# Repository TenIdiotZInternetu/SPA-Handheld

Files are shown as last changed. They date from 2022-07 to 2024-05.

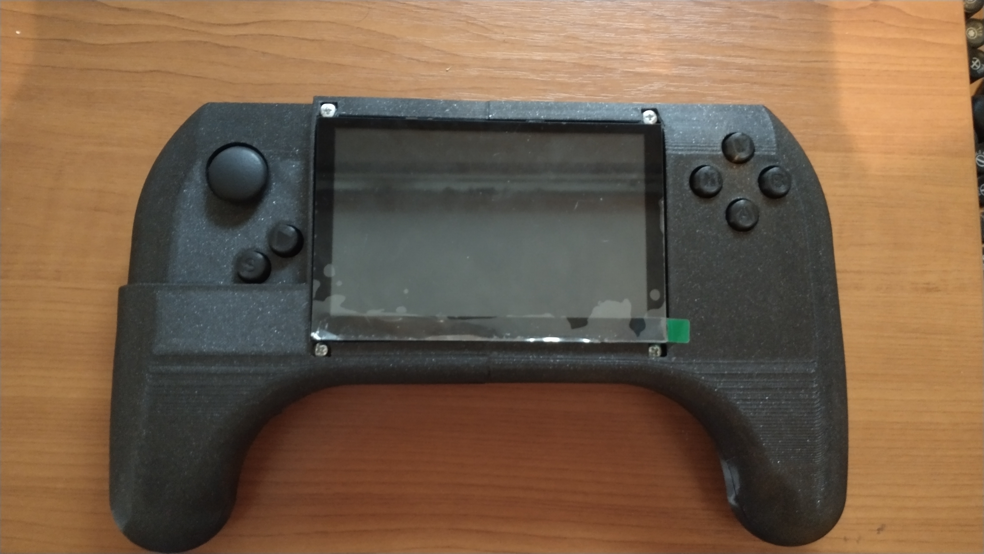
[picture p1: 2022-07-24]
IMG_20220422_183612783.jpg

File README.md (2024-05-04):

# SPA-Handheld

This is the main part of the Handheld Console project, a topic we chose for the Slovak Students' Professional Activities 2022.

All design files of the final product are contained here. The whole process of inspiration, designing PCB and 3D model and setting up the device is documented in the docx/pdf document.

## Subprojects

Task of the SPA included designing and programming the startup GUI and a game created in Pygame. Both found in the repos below.

* [**Bullet Hell (Videogame)**](https://github.com/TenIdiotZInternetu/SPA-Bullet-Hell)  
* [**GUI**](https://github.com/TenIdiotZInternetu/SPA-Bullet-Hell)

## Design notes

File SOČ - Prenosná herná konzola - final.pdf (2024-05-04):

STREDNÁ PRIEMYSELNÁ ŠKOLA STROJNÍCKA A ELEKTROTECHNICKÁ

ULICA FRAŇA KRÁĽA 20, 949 01 NITRA

PRENOSNÁ HERNÁ KONZOLA

Stredoškolská odborná činnosť

Číslo odboru: 11 informatika

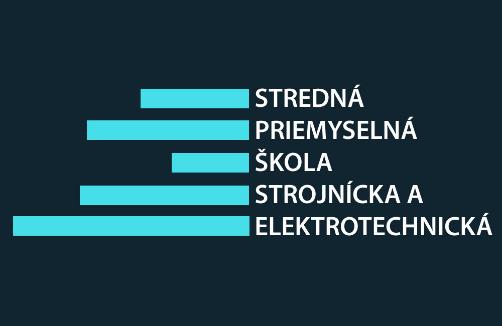
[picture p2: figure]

Riešitelia: Adam Balko

Jakub Brezovský

Nitra

2022

Ročník štúdia: štvrtý

STREDNÁ PRIEMYSELNÁ ŠKOLA STROJNÍCKA A ELEKTROTECHNICKÁ

ULICA FRAŇA KRÁĽA 20, 949 01 NITRA

PRENOSNÁ HERNÁ KONZOLA

Stredoškolská odborná činnosť

Číslo odboru: 11 informatika

Riešitelia: Adam Balko

Jakub Brezovský

Nitra

2022

Ročník štúdia: štvrtý

Školiteľ: PaedDr. Peter Antala

Čestné vyhlásenie

Vyhlasujeme, že prácu na tému Prenosná herná konzola sme vypracovali samostatne,

s použitím uvedených literárnych zdrojov. Sme si vedomí zákonných dôsledkov, ak v nej

uvedené údaje nie sú pravdivé.

Adam Balko | Jakub Brezovský

Poďakovanie

Touto cestou by sme sa chceli poďakovať školiteľovi práce PaedDr. Petrovi Antalovi za pomoc pri písaní a realizácii práce SOČ a taktiež Jakubovi Gálovi za užitočné rady pri jej

realizácii.

## OBSAH

ZOZNAM SKRATIEK A CUDZÍCH POJMOV

Bluetooth – protokoly pre bezdrôtovú komunikáciu na krátke vzdialenosti.

Boot – súbor procesov prebiehajúcich pri spúšťaní OS.

CAD (Computer Aided Design) – softvér na tvorbu 2D alebo 3D grafického znázornenia.

CAE (Computer Aided Engineering) – softvér určený na analýzy a simulácie.

CAM (Computer Aided Manufacturing) – softvér na vygenerovanie kódu pre CNC stroje.

Debian – jeden z operačných systémov dostupných pre Linux.

Debugovanie – kontrola funkčnosti programu a odstraňovanie chýb.

DPS – doska plošných spojov

DS (Dual Screen) – prenosná herná konzola od spoločnosti Nintendo.

DVD (Digital Video Disc) – optické pamäťové úložisko.

Emulátor – program pre spúšťanie softwaru na platformách, pre ktoré nebol určený.

FPS (Frames per Second) – počet vykreslených snímok za sekundu.

Game Boy – prenosná herná konzola od spoločnosti Nintendo.

GPIO (General-Purpose Input/Output) – rozhranie pre detekciu digitálnych výstupov a

vstupov Raspberry.

GUI (Graphical User Interface) – spôsob ovládania zariadenia cez grafické ikony

Handheld (z angl. „v rukách držaná“) – prenosná herná konzola.

Hard disk (Pevný disk) – magnetické pamäťové úložisko s veľmi veľkou kapacitou.

Hardware – fyzická časť počítača.

HDMI (High-Definition Multimedia Interface) – kábel pre prenos digitálneho zvuku a obrazu.

Hitbox – oblasť spritu schopná detegovať kolízie.

Image (obrázok) – vlastnosť spritu v Pygame, vizuálna reprezentácia objektu.

Joy-con – primárny herný ovládač konzoly Nintendo Switch.

Joystick / thumbstick – analógová kruhová ovládacia páka.

Linux – voľne šíriteľné jadro operačného systému.

Objekt – koncept v programovaní, dátový typ so špecifickými vlastnosťami a metódami.

OS – operačný systém.

Pin – krátky vodivý vývod konektora.

PIXEL (niekedy len „X“) – grafické užívateľské prostredie Raspberry Pi OS.

PSP (Playstation Portable) – prenosná herná konzola od spoločnosti Sony.

Pygame – sada modulov pre programovanie hier v Pythone.

Python – vysoko-úrovňový programovací jazyk.

Raspbian (Raspberry Pi OS) – odroda operačného systému Debian od Raspberry Pi.

RasPi (Raspberry Pi Zero 2 W) – jednodoskový mikropočítač.

Rect (rectangle, obdĺžnik) – vlastnosť spritu v Pygame, obsahuje jeho rozmery a polohu.

RetroPie – aplikácia, zbierka emulátorov starých herných konzol pre Raspberry Pi.

ROM (Read-Only Memory) – neprepisovateľná pamäť.

SD karta (Secure Digital Card) – flash pamäťové úložisko.

SDL (Simple DirectMedia Layer) – vývojová | knižnica | pre prácu | so vstupnými

a výstupnými zariadeniami.

Skript – krátky samostatne bežiaci program.

Software – programová časť počítača.

Sprite – sebestačný viditeľný objekt v Pygame.

SSH (Secure Shell) – protokol pre bezpečný prenos dát cez nechránené siete.

Switch (Nintendo Switch) – hybridná herná konzola od spoločnosti Nintendo.

Trieda (Class) – koncept v programovaní, definícia objektov rovnakého typu.

USB (Universal Serial Bus) – kábel pre komunikáciu a napájanie zariadení.

V (volt) – jednotka elektrického napätia.

Videohra – počítačová hra, digitálna hra.

Wi-Fi – protokoly pre lokálnu bezdrôtovú sieť.

WinSCP – program pre bezdrôtový prenos dát.

ZOZNAM ILUSTRÁCIÍ

SPŠSE Nitra | Úvod

8

ÚVOD

Videohry nás sprevádzajú už od detstva. Postupne prechádzala naša fascinácia z ich

hrania na vývoj a dizajn. S tým, samozrejme, prichádza aj záujem o herné konzoly

a počítače na ktorých bežia. Na elektrotechnickú strednú školu sme sa prihlásil práve

preto, aby sme nadobudli poznatky z hardwaru a softwaru, ktoré možno využijeme vo videohernom priemysle. Z tohto dôvodu sme si ako hlavnú tému našej práce SOČ vybrali

skonštruovanie vlastnej jednoduchej hernej konzoly, pre ktorú chceme vyvinúť aj vlastnú

videohru.

V predkladanej práci sa zameriavame na vývoj hardwarovej a softwarovej časti prenosnej

hernej konzoly. Pri písaní našej práce sme využívali poznatky zo štúdia na Strednej

priemyselnej škole strojníckej a elektrotechnickej v Nitre. Pri zhotovovaní zariadenia sme

čerpali najviac informácií z webových stránok a skúseností expertov na mikropočítače.

Hlavnou témou práce je zostrojenie prenosnej hernej konzoly, ktorá zahrňuje zbierku

emulátorov RetroPie, nami naprogramovanú hru v Pygame a grafické rozhranie schopné

spúšťať používateľom vytvorené hry.

Jednotlivé kapitoly našej práce postupne oboznámia čitateľa s problematikou prenosných

herných konzol, použitých aplikácií a mikropočítača Raspberry Pi, na ktorom bude celý

projekt pracovať. Popisujeme taktiež sadu modulov Pygame, aplikáciu RetroPie a softvéry

EAGLE a Fusion 360 ktoré sme použili pri vytváraní našej prenosnej hernej konzoly.

V druhej kapitole sú uvedené ciele našej práce a v ďalších kapitolách, ktoré sú určené pre

praktickú časť, popisujeme postup pri výrobe, vývoji, inštalácii, úprave a programovaní

aplikácií dôležitých pre dosiahnutie stanovených cieľov.

Sme toho názoru, že vytvorená prenosná herná konzola bude skvelým spôsob ako znova

prežiť svoje obľúbené hry z detstva, či už na cestách alebo z pohodlia domova, pričom

cenová dostupnosť a vysoká prispôsobiteľnosť Raspberry Pi s Linuxom ponúkne priestor

pre ďalšie experimentovanie a vylepšenie výrobku.

SPŠSE Nitra | Problematika a prehľad literatúry

9

### 1 PROBLEMATIKA A PREHĽAD LITERATÚRY

V prvej kapitole sa budeme venovať stručnej charakteristike herných konzol a oboznámime

čitateľov s jednodoskovým počítačom Raspberry Pi Zero 2 W, sadou modulov Pygame,

aplikáciou RetroPie a softvérmi EAGLE a Fusion 360, ktoré sme použili pri vytváraní našej

prenosnej hernej konzoly.

### 1.1 PRENOSNÁ HERNÁ KONZOLA

Herná konzola je elektronické zariadenie slúžiace na spúšťanie videohier z pamäťového

média (DVD, SD karta, Hard Disk, apod.), vysielanie audio a video signálu na výstupné

zariadenia (obrazovka, reproduktory) a ovládanie spustenej videohry pomocou herného

ovládača. Domáca herná konzola využíva externé vstupno-výstupné zariadenia.

Prenosná herná konzola (handheld) je typ hernej konzoly so zabudovanou obrazovkou,

ovládacími prvkami z herného ovládača, reproduktormi, poprípade inými vstupno-výstupnými

zariadeniami. Sú poháňane nabíjateľnými batériami a navrhované tak, aby boli čo

najkompaktnejšie. Na obrázku 1 je porovnanie veľkostí domácej hernej konzoly Playstation 4

(vľavo), jeho herného ovládača (v strede) a prenosnej konzoly Playstation Vita (vpravo).

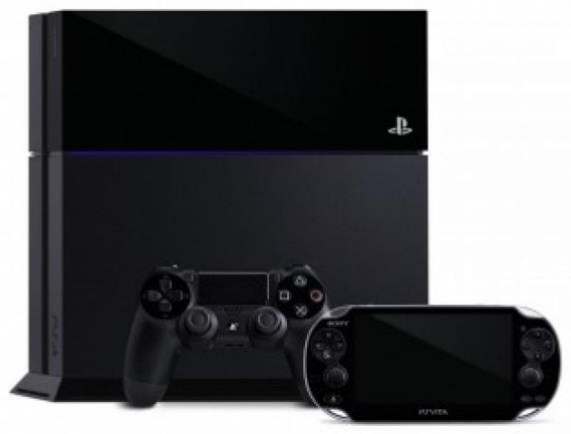
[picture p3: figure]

Obrázok 1 Domáca a prenosná herná konzola (playstationlifestyle, 2013)

Každý herný ovládač musí obsahovať tlačidlá na vykonávanie akcií špecifických pre danú

videohru. Od 90. rokov používajú všetky herné ovládače tzv. joysticky (niekedy tiež

thumbsticky). Sú to analógové zariadenia snímajúce vychýlenie páčky od stredu kruhovej

plochy pomocou 2 potenciometrov, 1 pre každú os pohybu. Pružina zaistí, aby sa páčka po

pustení vrátila do stredu kruhovej plochy. Novšie ovládače taktiež obsahujú prvky ako

SPŠSE Nitra | Problematika a prehľad literatúry

10

gyroskopy, vibračné motory, dotykový displej a iné. Výhodou herných konzol oproti

osobným počítačom (ktoré sú taktiež často používané na hranie videohier) je nižšia predajná

cena (väčšinou 300 – 500 €), garancia kompatibility medzi hardwarom a softwarom (čiže

elektronickými komponentami konzoly a videohrami) a minimálne zmeny v počiatočných

nastaveniach zariadenia. Používateľ však zaplatí nižším grafickým výkonom a nižším

počtom snímok za sekundu (bežne 30). Na hernej konzole taktiež nie je možné používať

profesionálny pracovný software. Handheldy sú typicky najlacnejšie a poskytujú najnižší

výkon, to však kompenzujú vyšším počtom vstupno-výstupných prvkov a schopnosťou hrať

videohry kdekoľvek a kedykoľvek.

Grafický výkon je dôležitý pre rýchle a verné vyobrazenie herného sveta, 2D a 3D animáciu,

simuláciu fyziky, výpočty spojené s hernými mechanizmami a umelou inteligenciou, čítanie

z pamäte, vykresľovanie obrazu na obrazovku a o mnoho viac. To všetko v reálnom čase.

Herné zariadenie musí byť schopné vykresliť na obrazovku aspoň 30 snímok každú sekundu

(FPS). To je minimálne množstvo potrebné na to, aby mozog nestihol reagovať na jednotlivé

snímky a vnímal ich ako plynulý pohyb. Vyššie FPS pre používateľa znamená, že hra reaguje

na jeho vstupy rýchlejšie. Naopak nižšie FPS spôsobuje trhavejší pohyb na obrazovke

a ťažšie ovládanie hry.

### 1.2 RASPBERRY PI ZERO 2 W

Raspberry Pi Zero 2 W (ďalej iba RasPi), je najnovší produkt z cenovo najdostupnejšej škály

jednodoskových mikropočítačov od Raspberry Pi (adafruit, 2021). Raspberry Pi Zero 2 W

uvedená na trh 28.10.2021 pri cene 15 $ ponúka až 5-násobný výkon svojho predchodcu

Označenie „W“ predstavuje schopnosť pripojenia k sieti Wi-Fi a Bluetooth.

Špecifikácie Raspberry PI Zero 2 W:

- 1GHz 4-jadrový 64-bit ARM procesor Cortex-A53,
- 512MB SDRAM,
- OpenGL ES 1.1, 2.0 grafické rozhranie,
- Porty: Mini HDMI, 2x Micro USB,
- CSI-2 konektor na kameru,
- 40-pinové GPIO rozhranie,
- 65mm x 30mm.

SPŠSE Nitra | Problematika a prehľad literatúry

11

Na činnosť je potrebný 5 V napäťový zdroj a Micro SD karta s vopred napáleným OS na báze

Linuxu. Raspberry Pi ponúka a odporúča odrodu Linuxovej distribúcie Debian,

Raspberry Pi OS, bežne nazývaný Raspbian (raspberrypi.com). SD karta slúži ako úložisko

pre všetky dáta na RasPi. Pre bežné použitie je nutné pripojiť obrazovku cez Mini HDMI

a klávesnicu na používanie terminálu cez Micro USB. V prípade negrafických aplikácii je

s RasPi možné komunikovať bezdrôtovo cez protokol SSH z osobného počítača. Veľmi

užitočné je rozhranie GPIO, ktoré slúži na prijímanie a odosielanie 3.3 V digitálnych signálov

napríklad zo snímačov, tlačidiel, LED, integrovaným obvodom apod.

Grafické jadro Broadcom VideoCore IV podporuje OpenGL 1.1, 2.0, ako aj dekódovanie

videa H.264, MPEG-4. Maximálne rozlíšenie je 1920 x 1080 pixelov, čiže full HD. Na

pripojenie monitora je k dispozícií mini HDMI konektor. Treba počítať aj s tým, že pamäť

512 MB je zdieľaná s grafickým jadrom, čiže operačný systém má k dispozícií len

približne 450 MB. Na obrázku 2 je popis pinov Raspberry PI Zero 2 W.

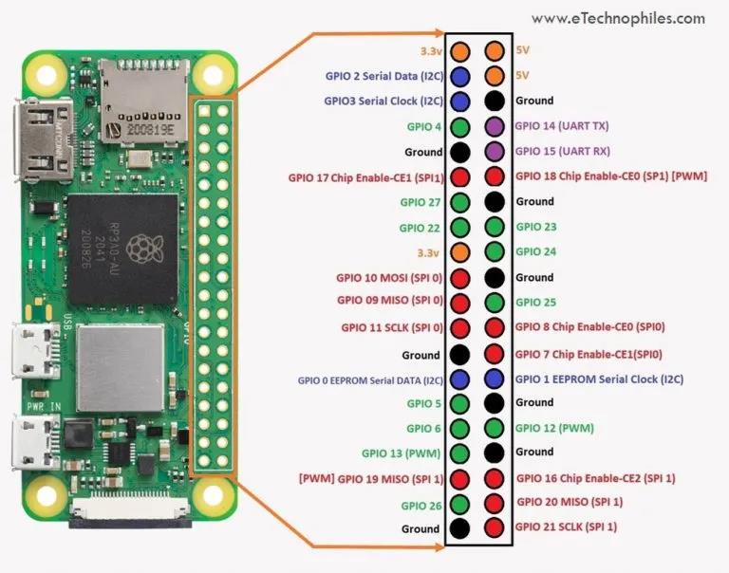
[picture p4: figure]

Obrázok 2 Raspberry PI Zero 2 W (eTechnophiles, 2022)

SPŠSE Nitra | Problematika a prehľad literatúry

12

### 1.3 PYGAME

Pygame je sada modulov pre programovací jazyk Python navrhnutých pre vývoj

videohier. Pygame pridáva funkcionalitu existujúcej knižnice SDL (pygame.org, 2022).

SDL je „multi-platformová vývojová knižnica navrhnutá pre nízkoúrovňový,“ (na úrovni

hardwaru), „prístup k audiu, klávesnici, myši, hernému ovládaču a grafickému hardwaru

skrz OpenGL a Direct3D“ (libsdl.org, 2022). Známe hry vytvorené pomocou knižnice

SDL sú napríklad Factorio alebo hry od spoločnosti Valve.

Základom každej hry je nekonečná slučka. V každom cykle tejto slučky Pygame číta

udalosti zo vstupných zariadení pomocou SDL, spracuje ich v používateľom napísaných funkciách a vykreslí nové informácie do okna, ktoré vytvoril. Dĺžka každého cyklu sa

určuje podľa požadovaného počtu FPS.

Dôležitým konceptom Pygame je trieda Sprite. Objekty, ktoré dedia z tejto triedy

predstavujú každú sebestačnú viditeľnú entitu, ktorou bude Pygame aplikácia

manipulovať, napríklad postavy, projektily, prvky používateľského rozhrania apod. Na

rozdiel od všeobecného pojmu, sprite v Pygame obsahuje okrem vizuálnej reprezentácie

objektu (image) aj informácie o jeho polohe a rozmeroch (rect), a metódu update, ktorá

prikazuje spritu ako sa chovať v každom cykle nekonečnej slučky.

Sprity podobného typu je možné priraďovať do dátovej štruktúry Group, ktorá umožňuje

masovo updatovať viacero spritov naraz, ako aj jednotlivými spritmi iterovať.

### 1.4 RETROPIE

RetroPie je aplikácia, ktorá buduje na Raspbian, EmulationStation, RetroArch a mnoho

ďalších projektoch, aby umožnil hranie arkádových, konzolových a klasických

počítačových hier s minimálnou prípravou. (retropie, 2022)

RetroArch a EmulationStation sú front-end programy pre prácu s emulátormi herných

konzol. Prinášajú grafické používateľské rozhranie, jednoduché spúšťanie emulovaných

hier, širokú škálu nastavení pre plynulý pochod programov a funkcionalitu nad rámec

pôvodných zariadení.

Emulátor je hardware alebo software, umožňujúci jednému počítačovému systému

(nazývanému hostiteľ) chovať sa ako iný počítačový systém (zvaný hosť). Emulátor

SPŠSE Nitra | Problematika a prehľad literatúry

13

typicky dovoľuje hostiteľovi spustiť software alebo používať periférne zariadenia

pôvodne navrhnuté pre hosťovský systém. (wikipedia – a, 2022)

RetroPie združuje mnoho emulátorov, medzi inými aj pre pôvodný Game Boy, a knižníc

potrebných pre vysokú kompatibilitu s počítačmi Raspberry Pi. Ovládateľný je širokou

škálou herných ovládačov alebo klávesnicou, ktoré sa dajú v rámci aplikácie

konfigurovať. RasPi je svojím výkonom schopné emulovať konzoly 2. až 5. generácie

(koniec 70-tych až koniec 90-tych rokov).

Samotné hry sú inštalované formou ROM obrazov. Ide o počítačové súbory obsahujúce

kópiu dát z ROM (Read-Only Memory) čipu, často z videoherných diskiet (wikipedia - b,

2022). Na používanie stačí ROM obrazy skopírovať v správnom formáte do priečinku

prislúchajúcemu konkrétnemu emulátoru.

### 1.5 EAGLE

EAGLE je návrhový softvér pre elektroniku od spoločnosti Autodesk, ktorý umožňuje

vytvoriť návrh DPS podľa schémy zapojenia a následne umožňuje vygenerovať dáta pre

výrobu samotnej DPS.

Samostný softvér sa skladá z editora schém, editora plošných spojov a editora knižníc.

Editor schém slúži na vytvorenie schémy zapojenia s možnosťou simulátora, vytvorenia

blokov a s elektronickou kontrolou nastavených pravidiel. Editor plošných spojov

synchronizuje schému s návrhom, poskytuje kontrolu návrhových pravidiel a pomocou

ďalších nástrojov výrazne zjednodušuje proces návrhu DPS. Editor knižníc obsahuje

databázu prvkov potrebných pre vytvorenie schémy návrh DPS.

### 1.6 FUSION 360

Fusion 360 je cloudový softvér od firmy Autodesk pre 3D CAD, CAM, CAE

modelovanie. Umožňuje vyvíjať výrobok v celom jeho procese od skice, cez návrh 3D

modelu, jeho testovanie, simulácie, vizualizácie až po výrobu. Pri modelovaní sa vytvára

časová os. Fusion 360 obsahuje nástroje, ktoré umožňujú skicovanie, priame

modelovanie, modelovanie povrchu, parametrické modelovanie, modelovanie sieťoviny,

voľné modelovanie, vykresľovanie, integráciu návrhu DPS, prácu s plechmi a zostavami.

Keďže je Fusion 360 kompatibilný s programom EAGLE, tak umožňuje do 3D modelu

importovať model našej DPS.

SPŠSE Nitra | Ciele práce

14

### 2 CIELE PRÁCE

Vlastniť prenosnú hernú konzolu bolo snom takmer každého chlapca. Avšak postupom

času sa pre nás stal záujmom nového poznania fakt, ako tieto malé zariadenia fungujú.

V súčasnosti, keď je možné vďaka pokroku zostrojiť doma vlastnú hernú konzolu, bolo

pre nás výzvou spolupodieľať sa na vytvorení takéhoto zariadenia.

Hlavným cieľom ktorý sme si stanovili pre našu prácu bolo zostrojiť prenosnú hernú

konzolu. Popri hlavnom ciele našej práce sme si stanovili aj nižšie uvedené čiastkové

ciele.

Čiastkové ciele:

- stručne | oboznámiť | čitateľov | s vysvetlením | pojmu | herná | konzola

a charakteristikou Raspberry PI Zero 2 W, Pygame a RetroPie,

- zostrojiť hernú konzolu s riadením pomocou Raspberry PI Zero 2 W,
- na vizuálne zobrazenie použiť 5" displej HDMI 800x480,
- ovládanie hernej konzoly zabezpečiť prostredníctvom joysticku a tlačidiel,
- ako pamäťové úložisko použiť SD kartu na Raspberry,
- prostredníctvom 3D tlače vytvoriť konštrukčné prvky hernej konzoly
- vytvoriť vlastné grafické používateľské rozhranie,
- umožniť spúšťanie hier naprogramovaných v Pygame,
- vytvoriť jednoduchú hru v Pygame,
- integrovať emulátor retro hier RetroPie.

SPŠSE Nitra | Materiál a metodika

15

### 3 MATERIÁL A METODIKA

V tretej kapitole našej dokumentácie sa zameriame na postup výroby hernej konzoly,

postup pri inštalácii operačného systému a niektorých dôležitých aplikácii. Popíšeme

prácu s Raspberry Pi a vývoj jednoduchej videohry pomocou Pygame.

### 3.1 BLOKOVÁ SCHÉMA PRENOSNEJ HERNEJ KONZOLY

Výrobnej fáze predchádzala prípravná fáza, ktorej podstatou bolo získavanie informácií a

materiálu pre náš projekt. Začiatkom výrobnej fázy bol nákres schémy v programe EAGLE,

návrh DPS a prvé pokusy o 3D model obalu. Súbežne s modelovaním obalu pracovali na vývoji

softvéru, zadali DPS do výroby a následne sme ju osádzali jednotlivými súčiastkami. Na

obrázku 3 je bloková schéma zariadenia. Podrobná schéma sa nachádza v Prílohe A.4.

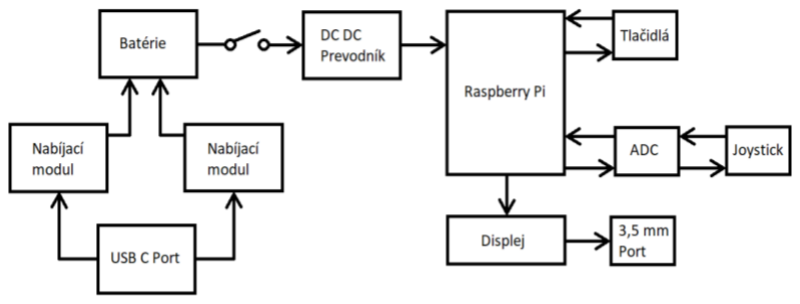
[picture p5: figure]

Obrázok 3 Bloková schéma prenosnej hernej konzoly

USB C port - slúži na prívod elektrickej energie do obvodov konzoly.

Nabíjacie moduly - nabíjajú batérie vhodným napätím.

Batérie - mobilné napájanie obvodu.

DCDC prevodník - znižuje jednosmerné napätie z batérií, chráni obvod pred

nedovoleným napätím.

Raspberry Pi – jadro celého obvodu, mikropočítač.

Displej – zobrazovacia jednotka.

3,5 mm port – audio výstup pre slúchadlá.

ADC (analog to digital converter) – prevádza analógový signál z joysticku na digitálny a naopak.

Joystick – vysiela analógový signál do ADC, spôsob pohybu v hre.

Tlačidlá - vysielajú digitálny signál do Raspberry Pi, rôzne funkcie v hre.

SPŠSE Nitra | Materiál a metodika

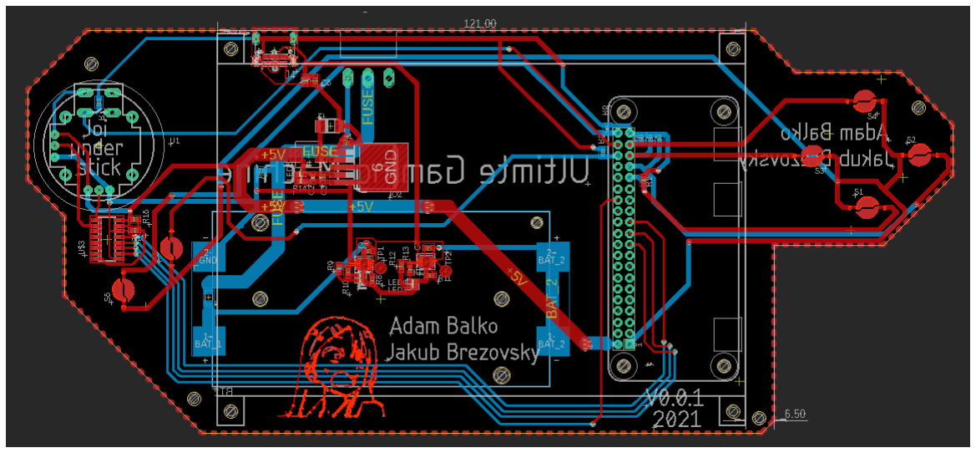
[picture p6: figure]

16

### 3.2 DOSKA PLOŠNÝCH SPOJOV

Návrh DPS sme realizovali pomocou návrhového softvéru pre elektroniku - EAGLE. Začali

sme nákresom schémy a následne sme prešli k návrhu samotnej DPS. Ako prvé sme načrtli

pôdorys displeja do stredu dosky. Napravo od displeja sme umiestnili primárne tlačidlá, zatiaľ

čo na ľavú stranu sme umiestnili joystick a systémové tlačidlá. Spínač, rovnako ako USB-C a

3,5 mm port sme umiestnili na horný okraj DPS. Socket pre batérie sme pre jeho veľké rozmery

umiestnili na spodnú stranu DPS.

Pre tlačidlá sme vytvorili vlastnú knižnicu v EAGLE editore súčiastok. Aby sa uhlíková vložka mohla dotýkať vodivých častí tlačidla, celý jeho povrch je potrebné označiť vrstvou tStop. Časti

dosky označené touto vrstvou nebudú pri výrobe pokryté izolačnou vrstvou (obrázok 4).

Obrázok 4 Návrh DPS

Keďže je nutné, aby bola DPS dvojvrstvová, nevyrábali sme ju sami, ale nechali sme ju na

mieru vyrobiť cez JLCPCB.com. Pre objednávku je potrebné nahrať súbor DPS v Gerber

formáte. Gerber súbory obsahujú všetky informácie potrebné pre výrobu DPS, ako napríklad umiestnenie dier, cestičiek, rozmery dosky, a pod. Úplný postup vytvárania

Gerber súboru nájdeme na stránke https://support.jlcpcb.com/article/137-how-to-generate-

gerber-and-drill-files-in-autodesk-eagle. (https://support.jlcpcb.com/article/137-how-to-generate-gerber-and-drill-files-in-autodesk-eagle) Po nahratí Gerber súboru sme ďalšie nastavenia

na stránke nemenili a objednávku sme potvrdili. Doska dorazila do 14 dní. Hotová DPS je

na obrázku 5.

SPŠSE Nitra | Materiál a metodika

17

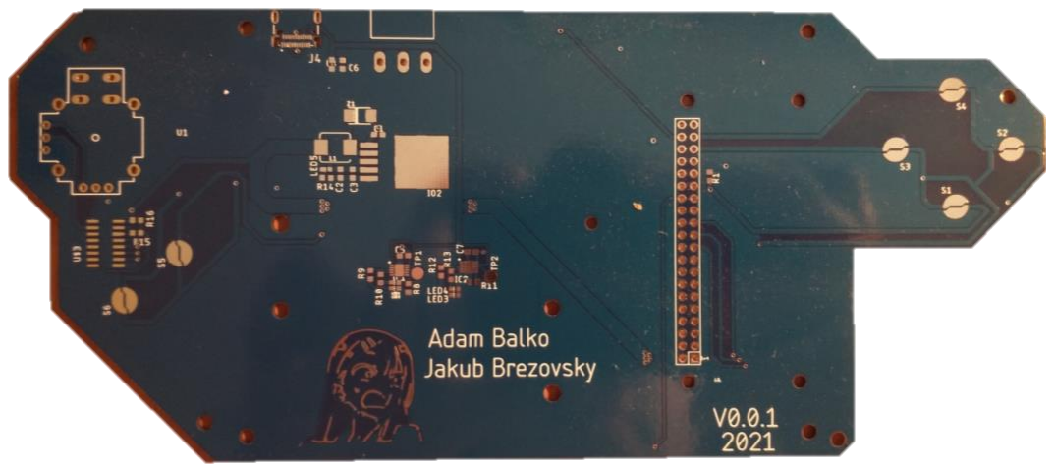
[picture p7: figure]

Obrázok 5 Vyrobená DPS

### 3.3 PRÍPRAVA PRE PRÁCU S RASPBERRY PI

Pre správne používanie RasPi pre naše účely je potrebné nainštalovať OS, nadviazať

bezdrôtové spojenie pomocou WinSCP a pozmeniť niektoré nastavenia. To si bližšie

popíšeme v tejto kapitole.

### 3.3.1 Inštalácia operačného systému

Prvým krokom je napálenie OS na SD kartu. Začneme inštaláciou na našu pracovnú stanicu

(napr. PC) Raspberry Pi Imager zo stránky https://www.raspberrypi.com/software/. SD

kartu vsunieme do čítačky SD na pracovnej stanici. Spustíme Raspberry Pi Imager.

V ponuke „CHOOSE OS“ si zvolíme podponuku „Raspberry Pi OS“ a možnosť

„Raspberry Pi OS (Legacy)“. RetroPie v dobe písania tejto dokumentácie nie je

prispôsobený verzii Raspbianu Bullseye z roku 2021 a nebude nainštalovaný úspešne.

Legacy znamená, že bude napálená staršia verzia Raspbian Buster. V ponuke

„CHOOSE STORAGE“ zvolíme našu SD kartu.

Klikneme na ikonu ozubeného kolieska a zaškrtneme nasledovné kolónky:

- „Enable SSH“
- „Set username and password“ a vložíme ľubovoľné prihlasovacie údaje
- „Configure wifi“ a vložíme prihlasovacie údaje wi-fi siete ku ktorej sa chceme

pripojiť

- „Set locale settings“ a zvolíme Keyboard layout „us“

Uložíme pomocou tlačidla „SAVE“ a OS napálime tlačidlom „WRITE“. Počkáme

niekoľko minút, kým sa OS napáli.

SPŠSE Nitra | Materiál a metodika

18

Po napálení otvoríme súbor boot/config.txt na SD karte podľa stránky našej HDMI

obrazovky (waveshare.com) doplníme na koniec nasledujúce riadky.

### 3.3.2 Nastavenie a používanie terminálu

SD karta je pripravená na vsunutie do RasPi. Po prepnutí vypínača na konzole sa na

obrazovke zobrazí výzva k zadaniu používateľského mena a hesla. Ide o rovnaké

prihlasovacie údaje, ktoré sme uviedli do sekcie „Set username and password“ pri

napaľovaní OS. Nabootuje sa PIXEL, grafické používateľské prostredie Raspbian.

RetroPie nie je možné spustiť, kým je PIXEL spustený. Riešením je nastaviť RasPi tak,

aby pri boote preskočil načítanie pracovnej plochy.

Na to musíme otvoriť terminál pomocou klávesovej skratky Ctrl+Alt+T. Použijeme

príkaz sudo raspi-config pre otvorenie nastavení RasPi. Zvolíme možnosti

„1 System Options“ > “S5 Boot / Auto Login” > “B2 Console Autologin” a potvrdíme

tlačidlom „<Finish>“. Pri výzve o reboot systému zvolíme možnosť „<Yes>“.

Od tohto momentu sa RasPi bude bootovať do príkazového riadku a nebude vyžadovať

prihlasovacie údaje. Dôležité príkazy pre navigáciu v termináli zahŕňajú:

- cd <názov priečinku> - vstup do priečinku
- cd .. – návrat do predchádzajúceho priečinku
- ls – výpis súborov v priečinku
- sudo <príkaz> - vykonanie príkazu ako správca (tzv. root)
- apt-get install <názov programu> - inštalácia programu z dpkg

databázy programov pre Linux

- git clone <url> - stiahnutie zdrojového kódu z databázy git
- python3 <.py súbor> - spustenie zdrojového kódu jazyka Python
- pip3 install <názov modulu> - inštalácia modulu pre jazyk Python
- sudo nano <názov súboru> - úprava textových súborov
- startx – vstup do pracovnej plochy PIXEL
- sudo raspi-config – vstup do nastavení RasPi

SPŠSE Nitra | Materiál a metodika

19

Pre používanie príkazov pip3 a git je ich najprv potrebné nainštalovať príkazmi sudo

apt-get install python3-pip a sudo apt install git.

### 3.3.3 Pripojenie pomocou SSH

SSH nám poslúži na zdieľanie súborov medzi pracovnou stanicou a RasPi, a na vzdialený

prístup k terminálu RasPi. Našou voľbou programu pre prácu s SSH je WinSCP pre jeho

jednoduchosť | a intuitívne | prvky. | Stiahnuť | ho | je | možné | zo | stránky

https://winscp.net/eng/download.php.

Po spustení nás uvíta prihlasovacie okno. Do kolónky „Host name“ vpíšeme lokálnu IP

adresu nášho RasPi. Zistiť ju môžeme pomocou príkazu ifconfig v termináli RasPi. Do

kolóniek „User name“ a „Password“ doplníme prihlasovacie údaje,. V kolónke „Port

number“ necháme číslo 22.

Niektoré príkazy vyžadujú oprávnenie správcu. To získame kliknutím na ponuku

„Advanced“ a zvolením podponuky „Shell“. Spomedzi možností ponuky „Shell“

vyberieme „sudo su -“. Klikneme na tlačidlo „OK“. Naše nastavenia uložíme pomocou

tlačidla „Save“ a pomocou tlačidla „Login“ sa spojíme s naším RasPi. Nadviazať spojenie

je možné iba ak je RasPi už spustené.

Celé používateľské rozhranie je na obrázku 6. Na ľavej strane vidíme súbory našej pracovnej

stanice. Na pravej strane vidíme súbory nachádzajúce sa na SD karte RasPi. Terminál môžeme

otvoriť pomocou ikonky terminálu v druhom riadku, alebo klávesovou skratkou Shift+Ctrl+T.

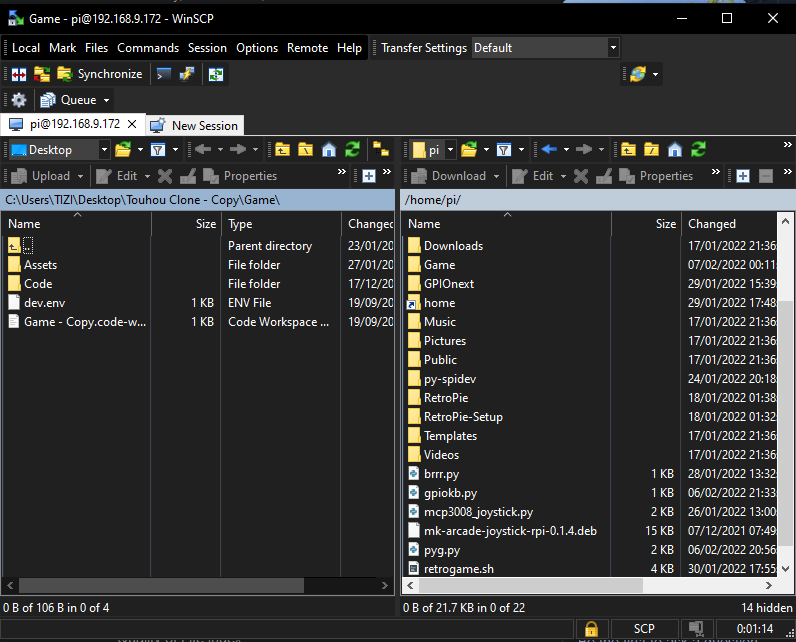
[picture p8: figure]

Obrázok 6 Používateľské rozhranie WinSCP

SPŠSE Nitra | Materiál a metodika

20

### 3.4 INŠTALÁCIA EMULÁTORA RETROPIE

V nasledujúcej kapitole si ukážeme, ako nainštalovať RetroPie a nastavenie GPIO pinov.

### 3.4.1 Konfigurácia GPIO vstupov

RetroPie nemá zabudované čítanie s GPIO vstupov, ku ktorým sú pripojené naše tlačidlá.

Jedným riešením je napísať externý skript, ktorý bude simulovať vstupy klávesnice, keď

sa bude na GPIO pine nachádzať napätie. Tento skript bude vždy bežať na pozadí.

Využijeme Python moduly keyboard a RPi.GPIO. Modul keyboard je potrebné

nainštalovať pomocou príkazu pip3 install keyboard. Na čítanie vstupov z ADC cez

SPI zbernicu sme využili modul Adafruit MCP3xxx, ktorý sme stiahli príkazom pip3

install adafruit-circuitpython-mcp3xxx. Časť kódu na detekciu analógových

vstupov je vidieť na obrázku 7.

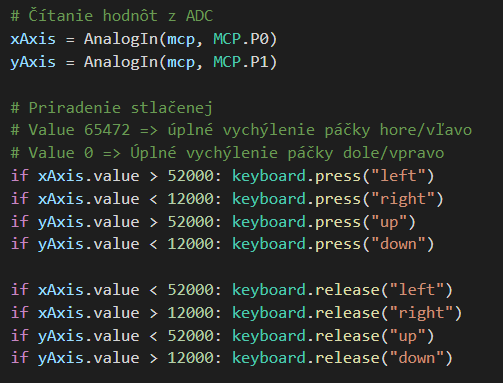
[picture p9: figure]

Obrázok 7 Časť skriptu gpiokb.py

Na používanie SPI zbernice je potrebné zmeniť mód pinov 9, 10 a 11 na alternatívny

vstup 0 vždy po boote RasPi. Uskutočníme tak v bash skripte, ktorého obsah je na

obrázku 8. Pred samotnou zmenou módu sme nastavili čakanie 20 sekúnd, aby sme

predišli zmene módu naspäť na východzí a inému nežiadanému správaniu.

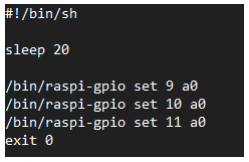
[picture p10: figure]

Obrázok 8 Skript setspi.sh

Súbory so skriptami nahráme do RasPi pomocou WinSCP. Aby spustili hneď pri boote

RasPi dopíšeme príkazy na ich spustenie do systémového súboru /etc/rc.local nad riadok

SPŠSE Nitra | Materiál a metodika

21

exit 0. | Ide | konkrétne | o príkazy | sudo python3 /home/pi/gpiokb.py &

a bash /home/pi/setspi.sh &.

### 3.4.2 Konfigurácia RetroPie

Pri inštalácii dodržujeme postup uvedený na stránke https://retropie.org.uk/docs/Manual-

Installation/. (https://retropie.org.uk/docs/Manual-Installation/) Pred inštaláciou programov je väčšinou vhodné aktualizovať OS príkazom

sudo apt update && sudo apt upgrade, no keďže RetroPie nie je kompatibilný

s najnovšou verziou Raspbian Bullseye, tento krok ignorujeme. Pokračujeme zmenou

lokalizačných nastavení a následným spustením inštalátora RetroPie podľa obrázku 9.

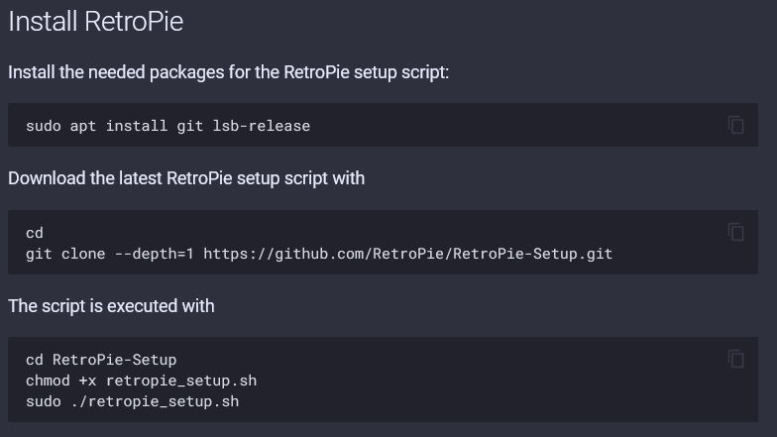
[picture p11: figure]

Obrázok 9 Postup pri spúšťaní inštalátora RetroPie (retropie, 2022)

Jednotlivé komponenty RetroPie sa dajú nainštalovať samostatne v sekcii „Manage

Packages“, no pre našu aplikáciu je vyhovujúce spustiť základnú inštaláciu možnosťou

„Basic Install“. Zvyšok inštalácie prebieha automaticky a trvá približne 6 až 8 hodín.

Po dokončení inštalácie spúšťame RetroPie z terminálu príkazom emulationstation.

Po prvom spustení sa nám zobrazí okno pre konfiguráciu vstupného zariadenia.

Podržaním ktoréhokoľvek z tlačidiel by mal program detegovať zariadenie

„KEYBOARD“, čiže klávesnicu. Nasleduje zoznam vstupov, tak ako na obrázku 16. Pri

každom z nich stlačíme prislúchajúce tlačidlo. V prípade „D-PAD“ tlačidiel posunieme

joystick do prislúchajúceho smeru. V prípade možnosti „HOTKEY ENABLE“ stlačíme

joystick. Pre vstupy nenachádzajúce sa na našom ovládači podržíme akékoľvek

z tlačidiel. V prípade chyby je možné vykonať konfiguráciu vstupov z hlavného menu

RetroPie stlačením tlačidla START a zvolením možnosti „CONFIGURE INPUT“.

SPŠSE Nitra | Materiál a metodika

22

Pridávanie hier prebieha kopírovaním ROM obrazov do prislúchajúceho emulátora

v priečinku /home/pi/RetroPie/roms. Po tomto kroku sa v hlavnom menu RetroPie

zobrazia ponuky emulátorov, ktoré obsahujú aspoň 1 hru vo svojom ROM priečinku a je

možné ich hrať. Ak sa žiadaný emulátor nenachádza v zozname ROM priečinkov, je ho

možné dodatočne nainštalovať v hlavnom menu zvolením možností „RetroPie“ >

„RETROPIE SETUP“ > „Manage packages“ > „Optional packages“.

### 3.5 VÝVOJ HRY V PYGAME

V nasledujúcich podkapitolách stručne popíšeme vývoj hry pomocou Pygame. Rozhodli

sme sa pre hru žánru bullethell. Pre tento žáner je typický voľný pohyb hrateľnej postavy

po 2 osiach. Nepriateľské postavy prichádzajú zvyčajne zhora a generujú veľmi veľké

množstvo projektilov. Hráč je vybavený veľmi rýchlymi vylepšiteľnými zbraňami

a obmedzeným počtom bômb, ktoré zaručujú hráčovi nezraniteľnosť. Jeho úlohou je

projektilom sa vyhýbať a poraziť hlavného nepriateľa (tzv. bossa) na konci úrovne.

V tejto kapitole si predstavíme iba najdôležitejšie triedy a koncepty pre fungovanie programu. Úplný zdrojový kód nami vytvorenej hry je v Prílohe A.1.

### 3.5.1 Inicializácia Pygame

Na písanie kódu sme si vybrali vývojové prostredie Visual Studio Code. Prvým krokom je

nainštalovať rozširujúci modul Pygame. Projekt bude rozdelený do 2 hlavných priečinkov:

- „Assets“ bude obsahovať všetky audiovizuálne prostriedky
- „Code“ bude obsahovať všetok zdrojový kód

Inicializáciu aplikácie sme rozdelili do 2 súborov:

- „AppSettings.py“ obsahuje globálnu konštantu GAME so základnými

parametrami aplikácie a inicializáciu okna s hrou

- „Startup.py“ obsahuje nahratie SDL knižníc, inicializáciu Pygame, prvej úrovne

a ďalšie prvotné nastavenia

Všetky súbory okrem Startup.py musia byť pripnuté ku koreňovej adrese projektu, aby

ich kompilátor považoval za súčasť projektu. Aplikáciu debugujeme spúšťaním

Startup.py. Na RasPi to vykonáme vstúpením do priečinku v ktorom sa Startup.py

nachádza a príkazom python3 Startup.py.

SPŠSE Nitra | Materiál a metodika

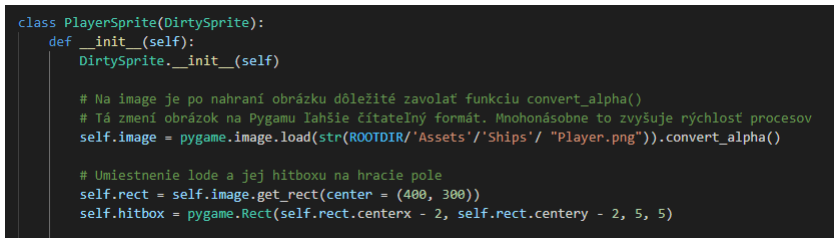
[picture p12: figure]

23

### 3.5.2 Hrateľná postava a jej ovládanie

Triedy postáv budú dediť z trieda DirtySprite, ktorá samotná dedí z triedy Sprite a dopĺňa

ju o užitočné spôsoby, ako s ňou manipulovať. Najprv spritu priradíme jeho image. Ten

sme vytvorili v grafickom editore Krita a umiestnili do priečinku Assets. Pomocou

funkcie get_rect() vytvoríme rect s rozmermi imagu. Pomocou parametru center určime

súradnice jeho polohy, a umiestnime ho tak na hracie pole.

Keďže sa na obrazovke bude nachádzať potenciálne stovky projektilov, bežnou praktikou

hier tohoto žánru je nastaviť hitbox (časť objektu ktorá deteguje kolízie s inými objektami)

na mnohonásobne menšiu veľkosť ako obrázok lode (červený rámik v obrázku 20).

V našom prípade sme vyrobili nový objekt typu Rect a jeho veľkosť sme nastavili na 5x5

pixelov. Zdrojový kód je na obrázku 10 a jeho presná poloha je na obrázku 11.

Obrázok 10 Nastavenie prvkov image, rect a hitbox hrateľnej postavy

Obrázok 11 Image hrateľnej postavy a jej hitbox

Pokračujeme vytvorením vlastností a stavov špecifických pre hrateľnú postavu.

Príkladom sú premenné na riadkoch 26-41 súboru Player.py v Prílohe A.1. Dôležitým

konceptom mnohých žánrov hier sú tzv. snímky nezraniteľnosti. Je viac než

pravdepodobné, že projektily, ktoré zasiahnu hráča, sa ho budú dotýkať dlhšie ako na

jednu snímku. Je tiež možné, že ho zasiahne viac projektilov naraz, ak so dostane do úzkej

situácie. Ak by sme odobrali zdravie hráčovi za každú snímku, hra by sa ukončila

SPŠSE Nitra | Materiál a metodika

24

v zlomku sekundy. Preto pri zásahu venujeme hráčovi zopár sekúnd počas, ktorých je

nezraniteľný. Indikujeme ich miernym blikaním postavy hráča.

Pre ovládanie postavy potrebujeme metódu, ktorá bude čítať GPIO vstupy v každom

cykle slučky, podobne ako skript gpiokb.py na obrázku 10. Táto metóda bude súčasťou

triedy UserInput(). Namiesto vytvárania klávesnicových vstupov budeme hodnotu na

GPIO pine zapisovať do vlastností globálnej konštanty USERINPUT.

Aby mohol hráčov sprite reagovať na vstupy, pridáme do jeho triedy metódu

control_player(), ktorá bude obsahovať podmienky pre každú z vlastností USERINPUT

a akciu, ktorá sa má vykonať ak sú splnené. Túto funkciu pridáme do update() metódy spritu

hráča. Ak sa zmení poloha rectu lode, musí sa zmeniť aj poloha jej hitboxu. Implementácia

control_player() sa nachádza na riadkoch 80-100 súboru Player.py v Prílohe A.1.

### 3.5.3 Vývoj úrovne

Trieda Level() bude jadrom celej aplikácie. Po inicializácii načíta všetky potrebné sprity.

Potom zaháji nekonečnú slučku, v ktorej bude všetky sprity updatovať, detegovať kolízie,

vytvárať udalosti počas priebehu úrovne a následne všetky zmeny vykresliť na obrazovku.

Hlavnými vlastnosťami budú queues, obsahujúca všetky sprity načítané do pamäte

a premenné typu LayeredDirty, ktoré dedia z triedy Group ale pracujú s objektmi typu

DirtySprite(). Tieto premenné budú obsahovať sprity, na ktoré bude aplikovaná funkcia

update() v každom cykle slučky. Načítať sprity do queues pred zahájením slučky a meniť

ich stav pridávaním a odoberaním z group je časovo oveľa menej náročne, ako ich

vytvárať a ničiť v slučke v reálnom čase. Riskujeme však vyplytvanie operačnej pamäte

pri načítaní veľkého množstva spritov. Počet načítaných spritov do queue určuje

maximálne množstvo spritov možné načítať na obrazovku.

Nasleduje inicializácia spritu Playfield. Ide o plochu s čiernym pozadím. Jej okraje budú

pre hráča nepriechodné. Nepriatelia a projektily príliš ďaleko za jej hranicou budú odstránené z ich group. Ďalej pridávame počítadlo cyklov, stavy úrovne, zoznamy metód

špecifických pre danú úroveň a metódu all_sprites.clear(), ktorá nastaví playfield ako

plochu na ktorú budú sprity vykresľované.

Sprity nahráme do pamäte po inicializácii úrovne zo súboru Startup.py. Dosiahneme to

vlastnosťou load_assets, do ktorej uložíme metódu pre načítanie spritov konkrétnej

SPŠSE Nitra | Materiál a metodika

25

úrovne. Samotný proces načítania spritov je vidieť na riadkoch 150-174 súboru

LevelClass.py v Prílohe A.1.

Ďalej zo Startup.py spustíme samotnú slučku metódou launch_stage(). Celá slučka sa dá

zhrnúť do niekoľkých metód, tak ako na obrázku 12.

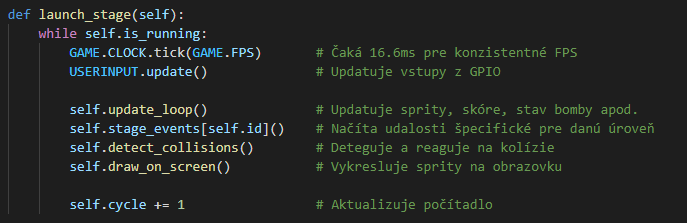
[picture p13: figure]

Obrázok 12 Procesy vykonané v každom cykle slučky

Plnú implementáciu použitých metód je možné nájsť v Prílohe A.1.

### 3.5.4 Vývoj nepriateľských postáv

Všetky nepriateľské postavy budú dediť z triedy EnemySprite, ktorá obsahuje základné metódy,

prevažne pre pridávanie a odstraňovanie spritov z groups a správanie po zásahu projektilom.

Metódy s predložkou „super“ sú referované v metódach tried jednotlivých typov nepriateľov.

Kľúčové metódy pre fungovanie EnemySprite sú bližšie popísané na riadkoch 22-88 súboru Enemy.py v Prílohe A.1.Ďalšie metódy v triede slúžia pre úpravu chovania počas hlavnej slučky.

Triedy jednoduchých nepriateľov budú obsahovať iba základné metódy. Triedam

zložitejších nepriateľov môžeme pridávať metódy podľa potreby. Napríklad GatlingDrone,

nepriateľ s rotačným guľometom obsahuje stav, v ktorom strieľa rapídnym tempom, a stav,

v ktorom sa jeho guľomet „chladí“. Každý stav je bližšie definovaný svojou metódou.

Objekt medzi stavmi prepína v metóde update podľa svojho vnútorného časovača.

Spôsob, akým sa nepriatelia pohybujú nie je definovaný v ich triede. Obsahujú vlastnosť

movement_pattern, ktorá im je priradená v hlavnej slučke programu. Pri výpočte pohybu

je pozícia objektu interpretovaná ako koreň smerového vektoru. Tento vektor potom

upravujeme podľa toho, akú krivku chceme aby náš objekt nasledoval. Krivky ako lineárna,

sínusová alebo sigmoidová funkcia sú bežnými vzormi pohybu pre nepriateľov aj

projektily. Preto je výhodné vytvoriť pre každú krivku vlastnú triedu v súbore

MovementPatterns.py, ktorá prijíma parametre ako uhol a rýchlosť pohybu, amplitúdu,

SPŠSE Nitra | Materiál a metodika

26

apod. a je prístupná pre všetky pohyblivé objekty. Každá z nich obsahuje funkciu update(),

ktorá vypočíta súradnice výsledného vektoru podľa základných princípov lineárnej algebry.

PyGame ponúka triedu Vector2 pre prácu s dvojrozmernými vektormi, ktorú sme rozšírili

o niekoľko užitočných funkcií v triede VectorPlus. Súčet výsledného vektoru

so súradnicami momentálnej pozície objektu predstavuje novú pozíciu, ktorou prepíšeme

stred rectu hýbaného objektu. Príkladom je výpočet nasledujúcej pozície na sínusovej

krivke, ktorej os je priamka pod ľubovoľným uhlom, ktorý je podrobnejšie popísaný na

riadkoch 49-83 súboru MovementPatterns.py v Prílohe A.1.

Vzor pohybu pre nepriateľov je upraviteľný kedykoľvek v hlavnej slučke. To ich robí

veľmi flexibilnými a znovu využiteľnými v širokej škále situácií. Projektily sú

jednoduchšie objekty, na obrazovke sa ich nachádza oveľa viac a sú pre hráča ďaleko

nebezpečnejšie. Aby ich správanie zostalo predvídateľné, ich vzor pohybu je pevne

určený v metóde spawn(). Definície tried projektilov sú uložené v súbore BulletTypes.py

a ich základné metódy sú podobné tým v triede EnemySprite.

### 3.6 GRAFICKÉ POUŽÍVATEĽSKÉ ROZHRANIE

Grafické používateľské rozhranie (ďalej iba GUI) slúži na to, aby používateľ

nepotreboval použiť klávesnicu počas celej doby bežného používania konzoly. Ide

o program napísaný pomocou Pygame, ktorý sa spustí počas bootu zariadenia. Jeho

kostrou bude ponuka aplikácií, ktorú môže používateľ jediným tlačidlom spustiť. Celý

program bude možné nájsť v Prílohe A.2.

Započatie aplikácie funguje rovnako pri vývoji hry v Pygame. Skopírovali sme obsah

súborov Statup.py a AppSettings.py z našej hry a vložili sme ho do súboru Startup.py

v priečinku GUI. Odstránili sme riadky referujúce na úroveň hry a globálnu premennú

GAME sme premenovali na APP.

MainMenu bude trieda obsahujúca hlavnú slučku. Jej vlastnosť options bude obsahovať

objekty triedy MenuOption. Vlastnosti tejto triedy budú obrázok viditeľný v menu, text

zobrazený v menu, ak si používateľ danú možnosť zvolil. Dôležitá je vlastnosť command,

obsahujúca príkaz potrebný na spustenie aplikácie v termináli.

Pred započatím slučky sa v inicializácii MainMenu spustí metóda load_options(), ktorá

číta podpriečinky v priečinku ./GUI/Options. Každý z týchto podpriečinkov predstavuje

SPŠSE Nitra | Materiál a metodika

27

jednu aplikáciu. Musí obsahovať obrázok aplikácie nazvaný „image.png“ a textový súbor

„data.txt“, ktorého obsah je v správnom formáte. Tieto dva súbory sú predané

novovytvorenému objektu MenuOption a uložené do jeho vlastností.

V hlavnej slučke sa nachádza metóda event_loop(), ktorá v prípade pohnutia joysticka

nahor alebo nadol zmení index práve zvolenej možnosti o 1 a nastaví vlastnosť cur_option na možnosť s týmto indexom. Ďalej zavolá metódu update_thumbnails(),

ktorej úlohou je vziať zo zoznamu options 2 objekty pred a 4 objekty za spomínaným

indexom a vykresliť ich na obrazovku ich image v správnej veľkosti na predom

definovanú pozíciu. Tieto objekty sú uložené do zoznamu visible_options.

Stlačením tlačidla „A“ spustíme aplikáciu tak, že najprv zavrieme okno Pygame metódou

pygame.display.quit(), spustíme príkaz cur_option.command metódou subprocess.call()

a následne ukončíme všetky procesy GUI pomocou pygame.quit(). Keďže po boote

musíme 20 sekúnd čakať na nastavenie GPIO vstupov konzoly, môžeme pred spustením

hlavnej slučky vykresliť jednoduchú načítaciu obrazovku.

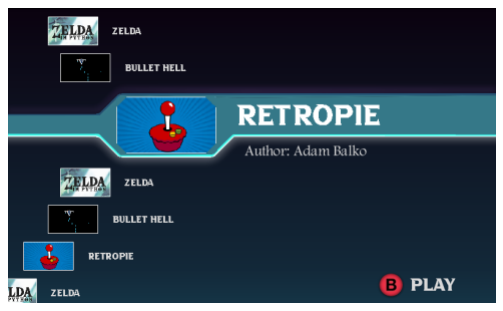
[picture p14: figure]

Obrázok 13 Grafické používateľské rozhranie

### 3.7 KONŠTRUKČNÉ PRVKY PRENOSNEJ HERNEJ KONZOLY

Konštrukčnými prvkami našej konzoly sú obal, ktorý zakrýva elektronické časti a

tlačidlá, ktorými sa stláčajú vodivé membrány. Všetky konštrukčné prvky sú navrhnuté v

3D modelovacom programe Fusion 360 od spoločnosti Autodesk a vytlačené na

3D tlačiarni Creality Ender 3 pro s použitím PLA filamentu.

V procese tvorby konštrukčných prvkov sme vytvorili viacero verzií, ktoré sme postupne

vylepšovali a odstraňovali nedostatky zistené ich používaním. Súčasná použitá verzia má

poradové číslo 5. Počas návrhu sme sa snažili zohľadniť ergonómiu tvaru, rozmery,

rozloženie jednotlivých prvkov vo vnútri aj na povrchu obalu. Obrázková dokumentácia

jednotlivých verzií je v Prílohe B.

SPŠSE Nitra | Výsledky práce

28

### 4 VÝSLEDKY PRÁCE

Výsledkom našej práce je funkčná prenosná herná konzola riadená mikropočítačom

Raspberry Pi Zero 2 W. Dizajn hardwarovej časti, dosku plošných spojov aj obal konzoly,

sme navrhli sami pomocou našich vedomostí o ovládačoch herných konzol. Využili sme

pri tom programy EAGLE a Fusion 360. Dosku sme osádzali ručne, obal sme vytlačili na

3D tlačiarni Ender 3.

Software Raspberry Pi beží na operačnom systéme Raspberry Pi OS. Zahrňuje videohru Bullet

Hell a grafické používateľské prostredie úplne unikátne pre naše zariadenie. Obe aplikácie boli

naprogramované v programovacom jazyku Python s použitím modulov Pygame. Všetky

grafické prvky sme vyrobili v grafickom editore Krita. Zariadenie je taktiež schopné emulovať

videohry herných konzol 2. až 5. generácie pomocou aplikácie RetroPie. Kompatibilné

softwarové prostredie sme dosiahli úpravou súborov Raspberry Pi OS programom WinSCP.

Konečná cena našej prenosnej hernej konzoly je 169,99 €. Najdrahšou položkou je 5" dotykový

displej v hodnote 54,49 €, ktorý spotreboval takmer tretinu nášho rozpočtu. Výberom iného

displeja sa môže cenu razantne znížiť, keďže jeho dotykovú funkciu v súčasnosti nevyužívame.

Spomedzi herných konzol dnešnej generácie je najlacnejšie Nintendo Switch, ktoré sa na

Alza.sk predáva za 289,90 €, čo je o 70 % viac ako naše náklady na výrobu. Nintendo

Switch však ponúka ďaleko vyšší výkon a funkcionalitu vďaka jeho univerzálnym

joy-conom. V súčasnosti je ešte ťažké povedať kde ležia limity našej hernej konzoly, no

svojím grafickým výkonom nám najviac pripomína Nintendo DS, prenosnú hernú

konzolu z roku 2004, ktorá síce tiež podporovala jednoduchú 3D grafiku, ale na

obrazovkách s 3-krát nižším rozlíšením. Po inflácii sa jej cena pohybuje okolo 190 €.

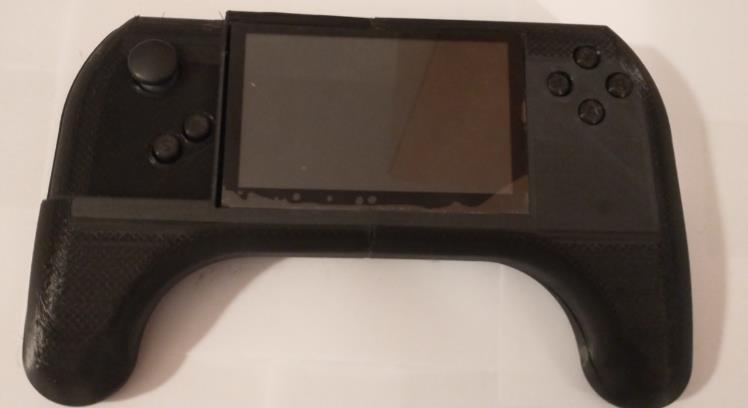
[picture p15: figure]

Obrázok 14 Prenosná herná konzola

SPŠSE Nitra | Záver

29

ZÁVER

Herné konzoly a ich prenosné verzie nestrácajú svoje čaro ani v súčasnosti. Stále sú na

trhu s elektronikou veľmi zaujímavým artiklom aj z hľadiska finančného zisku. Nám

tento projekt priniesol neoceniteľné skúsenosti z oblasti spolupráce, plánovania

pracovných činností, vývoja hardvéru a softvéru a samozrejme v neposlednom rade sme si prehĺbili svoje zručnosti pri osádzaní dosky plošných spojov, 3D modelovaní a získali

sme nové vedomosti z oblasti elektroniky, práce so softvérom EAGLE a Fusion 360

a taktiež v programovaní s Python a Pygame.

V našej práci sme sa zamerali na výrobu prenosnej hernej konzoly. V prvej kapitole našej

práce predkladáme stručnú charakteristiku herných konzol, popisujeme Raspberry Pi

Zero 2 W, Pygame, RetroPie, EAGLE a Fusion 360.

Vyrobili sme funkčné zariadenie, ktoré má riadenie zabezpečené pomocou Raspberry Pi

Zero 2 W, na vizuálne zobrazenie používa 5" displej HDMI 800x480, na ovládanie hernej

konzoly slúži joystick a tlačidlá, ako pamäťové úložisko sme použili SD kartu na

Raspberry Pi a prostredníctvom 3D tlače sme vyrobili konštrukčné prvky hernej konzoly.

Naša herná konzola umožňuje spúšťať hry naprogramované v Pygame, vytvorili sme

jednoduchú hru v Pygame a obsahuje integrovaný emulátor retro hier RetroPie.

Pri vývoji a výrobe prenosnej hernej konzoly sme využívali odbornú literatúru, poznatky

zo štúdia na Strednej priemyselnej škole strojníckej a elektrotechnickej v Nitre a vlastné

skúsenosti.

Veríme, že prenosná herná konzola bude patriť medzi tie zaujímavejšie zariadenia a stane

sa zaujímavou inšpiráciou pre iné projekty ďalších žiakov.

SPŠSE Nitra | Zhrnutie

30

ZHRNUTIE

Cieľom našej práce bolo oboznámiť čitateľov so stručnou charakteristikou herných

konzol, popisom základných vlastností Raspberry Pi Zero 2 W použitého na zostavenie

prenosnej hernej konzoly, sadou modulov Pygame, aplikáciou RetroPie a softwarov

EAGLE a Fusion 360.

Hlavným cieľom bolo vytvoriť hardvérovú časť prenosnej hernej konzoly pomocou

Raspberry PI Zero 2 W, s 5" displejom HDMI 800x480, joystickom a tlačidlami na

ovládanie, pamäťovým úložiskom a krytom s ďalšími konštrukčnými prvkami vyrobenými

pomocou 3D tlače s jej softvérovým vybavením pozostávajúcim z vlastného grafického

používateľského rozhrania s možnosťou spúšťania hier naprogramovaných v Pygame,

vytvorenou vlastnou hrou v Pygame a integrovaným emulátorom retro hier RetroPie.

Výsledkom našej práce je funkčné zariadenie prenosnej hernej konzoly.

Vzhľadom k týmto cieľom konštatujeme, že sa nám podarilo naplniť všetky stanovené

ciele našej práce.

SPŠSE Nitra | Zoznam bibliografických odkazov

31

ZOZNAM BIBLIOGRAFICKÝCH ODKAZOV

Adafruit. 2021. Raspberry Pi Zero 2 W [online]. [cit: 2022-02-11]. Dostupné na internete: <https://www.adafruit.com/product/5291>

AMOS, Evan. 2010. File:Nintendo-DS-Lite-w-stylus.png [online]. [cit: 2022-02-10]. Dostupné na internete: <https://commons.wikimedia.org/wiki/File:Nintendo-DS-Lite-w-stylus.png> (https://commons.wikimedia.org/wiki/File:Nintendo-DS-Lite-w-stylus.png)

DORNBUSH, Jonathan; SIRANI, Jordan. 2020. Update: Comparing the Price of Every Game Console, With Inflation [online]. [cit: 2022-02-10]. Dostupné na internete: <https://www.ign.com/articles/comparing-the-price-of-every-game-console-with-inflation> (https://www.ign.com/articles/comparing-the-price-of-every-game-console-with-inflation)

DUNNING, Jason. 2013. New PS4 & PS Vita Games: Binding of Isaac: Rebirth, N++, Guns of Icarus Online, Rogue Legacy, Volume (Update: N++ Planned for Vita) [online]. [cit: 2022-02-09]. Dostupné na internete: <https://www.playstationlifestyle.net/2013/08/20/new-ps4-ps-vita-games-binding-of-isaac-rebirth-n-guns-of-icarus-online-rogue-legacy-volume/> (https://www.playstationlifestyle.net/2013/08/20/new-ps4-ps-vita-games-binding-of-isaac-rebirth-n-guns-of-icarus-online-rogue-legacy-volume/%3e)

eTechnophiles. 2022. Raspberry Pi [online]. [cit. 2022-03-02]. Dostupné na internete:

<https://www.etechnophiles.com/category/raspberry-pi/>

KAIN, Erik. 2017. Nintendo Switch Review: To Buy Or Not To Buy, That Is The Question [online]. [cit. 2022-02-12] Dostupné na internete: <https://www.forbes.com/sites/games/2017/03/01/nintendo-switch-review-to-buy-or-not-to-buy-that-is-the-question/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> (https://www.forbes.com/sites/games/2017/03/01/nintendo-switch-review-to-buy-or-not-to-buy-that-is-the-question/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)

KOHLER, Chris. 2017. Review: Nintendo Switch [online]. [cit: 2022-02-10]. Dostupné na internete: <https://www.wired.com/2017/03/review-nintendo-switch/>

libsdl.org. About SDL [online]. [cit. 2022-02-11] Dostupné na internete: <https://www.libsdl.org/index.php>

LYNCH, Ryan. 2018. Retro Gaming with Raspberry Pi: RetroPie vs. RecalBox [online]. [cit. 2022-02-10]. Dostupné na internete: <https://www.maketecheasier.com/retropie-vs-recalbox/>

Nintendo. 1983. Game Boy Compact Video Game System Owner’s Manual. Dostupné na internete: <https://www.flickr.com/photos/30348074@N00/5439386983/in/album-72157626034398554/> (https://www.flickr.com/photos/30348074@N00/5439386983/in/album-72157626034398554/)

Ollen Ollen. 2018. Battle Against L.T. Surge! - Pokemon Red Part #19 [online]. [cit. 2022-02-10]. Dostupné na internete: <https://www.youtube.com/watch?v=9mPJFnjjMsU>

SPŠSE Nitra | Zoznam bibliografických odkazov

32

psp-gamesreview. 2010. PSP Limited Edition God of War: Ghost of Sparta Entertainment Pack [online]. Dostupné na internete: <http://psp-gamesreview.blogspot.com/2010/11/psp-limited-edition-god-of-war-ghost-of.html> (http://psp-gamesreview.blogspot.com/2010/11/psp-limited-edition-god-of-war-ghost-of.html)

Pygame. About [online]. [cit. 2022-02-11]. Dostupné na internete: <https://www.pygame.org/wiki/about>

Raspberry Pi. 2021. Raspberry Pi Zero 2 W [online]. [cit: 2022-02-11]. (b) Dostupné na internete: <https://www.raspberrypi.com/products/raspberry-pi-zero-2-w/>

Raspberry Pi. Operating system images [online]. [cit: 2022-02-11]. (a). Dostupné na internete: <https://www.raspberrypi.com/software/operating-systems/>

RetroPie. Raspbian [online]. [cit: 2022-02-12]. (b). Dostupné na internete: <https://retropie.org.uk/docs/Manual-Installation/>

RetroPie. Welcome [online]. [cit: 2022-02-11]. (a) Dostupné na internete: <https://retropie.org.uk/>

WaveShare. 2020. 5inch HDMI LCD (H) [online]. [cit: 2022-02-12]. Dostupné na internete: <https://www.waveshare.com/wiki/5inch_HDMI_LCD_(H)>

Wikimedia. 2009. File:Wikipedia gameboyclassic.jpg [online]. [cit. 2022-02-10]. Dostupné na internete:
<https://commons.wikimedia.org/wiki/File:Wikipedia_gameboyclassic.jpg>

Wikipedia. Emulator [online]. [cit: 2022-02-11]. (b). Dostupné na internete: <https://en.wikipedia.org/wiki/Emulator>

Wikipedia. List of best-selling game consoles [online] [cit. 2022-02-10]. (a). Dostupné na internete: <https://en.wikipedia.org/wiki/List_of_best-selling_game_consoles>

Xbox. Xbox Wireless Controller [online]. [cit. 2022-02-09]. Dostupné na internete: <https://www.xbox.com/en-US/accessories/controllers/xbox-wireless-controller>

YOKOI, Gunpei. 1997. Gunpei Yokoi x Yukihito Morikawa – 1997 Developer Interview. [cit. 2022-02-10]. Dostupné na internete: <https://shmuplations.com/yokoi/>

YUAN, Michael. 2020. How to Build a Personal Dev Server on a $5 Raspberry Pi [online]. [cit. 2022-02-10]. Dostupné na internete: <https://www.freecodecamp.org/news/build-a-personal-dev-server-on-a-5-dollar-raspberry-pi/> (https://www.freecodecamp.org/news/build-a-personal-dev-server-on-a-5-dollar-raspberry-pi/)

ZOZNAM PRÍLOH

Príloha A | CD nosič
Príloha B | Fotodokumentácia projektu herná konzola
Príloha C | Zoznam súčiastok
Príloha D | Cenová kalkulácia nákladov

PRÍLOHA A

CD NOSIČ

Priložené CD obsahuje:

A.1 | Zdrojový kód hry Bullet Hell
A.2 | Zdrojový kód GUI
A.3 | Ostatné skripty
A.4 | Súbory so schémou a návrhom DPS
A.5 | Súbory s návrhom konštrukčných častí

PRÍLOHA B

FOTODOKUMENTÁCIA PROJEKTU HERNÁ KONZOLA

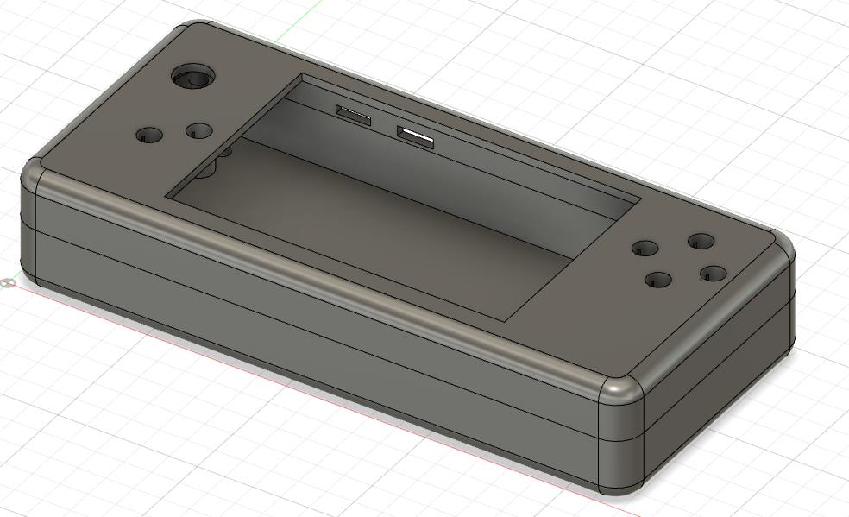
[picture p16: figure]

Obrázok B 1 Prvá verzia obalu hernej konzoly

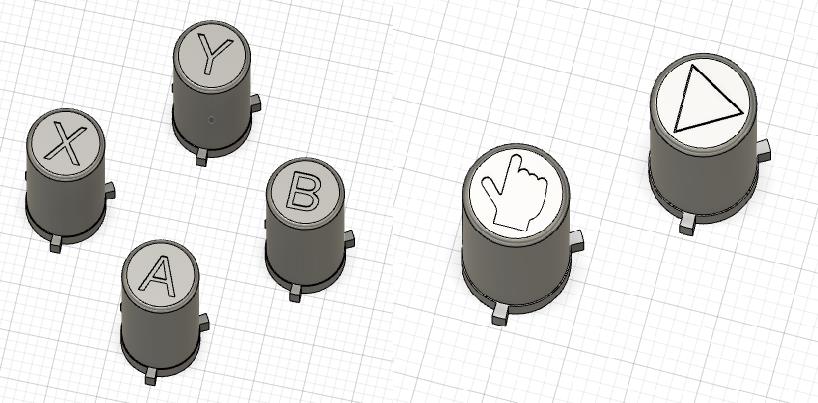
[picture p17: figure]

Obrázok B 2 Tlačidlá pre vodivé membrány

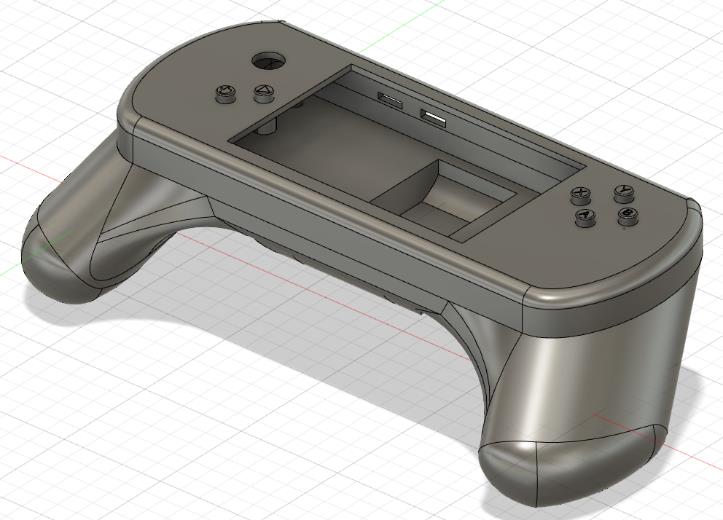
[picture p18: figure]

Obrázok B 3 Obal hernej konzoly – verzia 2

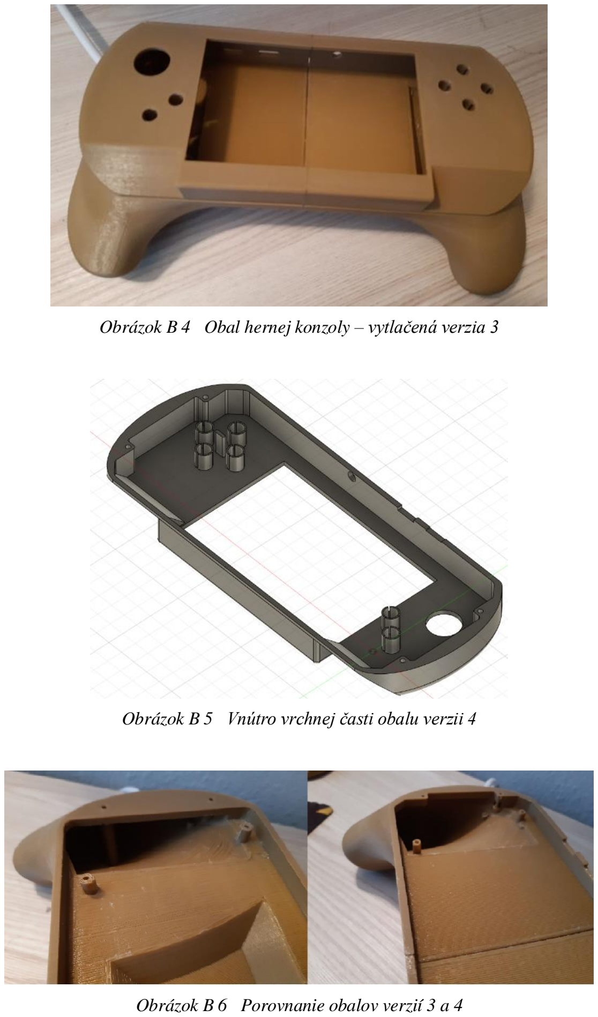
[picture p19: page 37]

Obrázok B 4 Obal hernej konzoly – vytlačená verzia 3

Obrázok B 5 Vnútro vrchnej časti obalu verzii 4

Obrázok B 6 Porovnanie obalov verzií 3 a 4

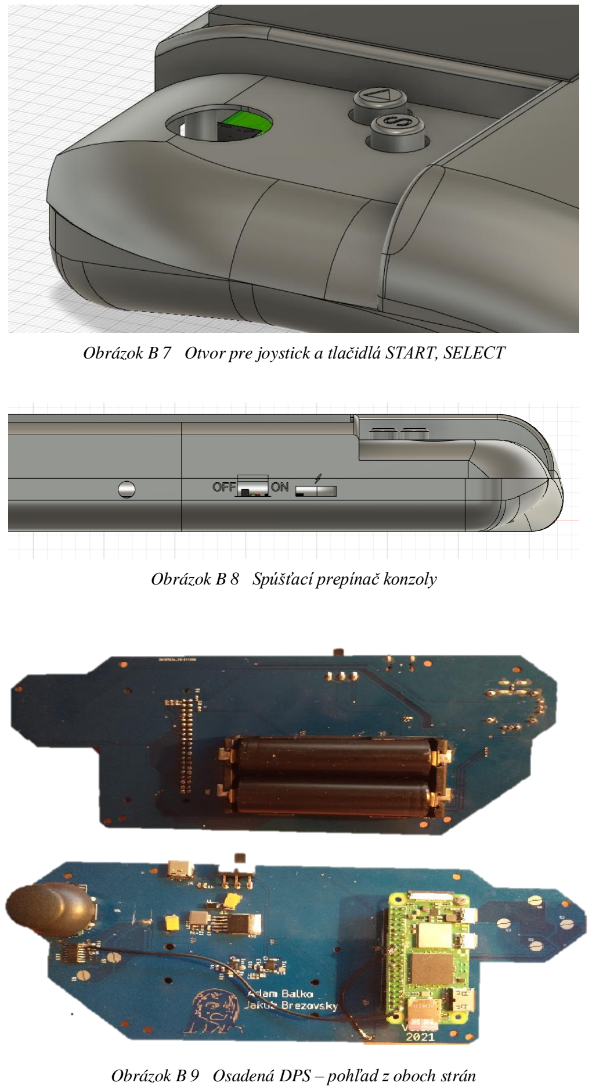
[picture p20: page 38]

Obrázok B 7 Otvor pre joystick a tlačidlá START, SELECT

Obrázok B 8 Spúšťací prepínač konzoly

Obrázok B 9 Osadená DPS – pohľad z oboch strán

PRÍLOHA C

ZOZNAM SÚČIASTOK

Partlist

Exported from Handheld.sch at 12. 2. 2022 16:03

EAGLE Version 9.6.1 Copyright (c) 1988-2020 Autodesk, Inc.

Assembly variant:

Part | Value | Device | Package
BT1 | 1048P | 1048P | BAT_1048P
C1 | 330n | C-EUC0603 | C0603
C2 | 220n | C-EUC0603 | C0603
C3 | 100nF | C-EUC0603 | C0603
C4 | 100n | C-EUC0603 | C0603
C5 | 100nF | C-EUC0603 | C0603
C6 | 100nF | C-EUC0603 | C0603
C7 | 100nF | C-EUC0603 | C0603
C8 | 100nF | C-EUC0603 | C0603
F1 | 5A | 3413.0113.22 | 3413.0113.22
IC1 | BQ24080DRCR | BQ24080DRCR | SON50P300X300X100-11N
IC2 | BQ24080DRCR | BQ24080DRCR | SON50P300X300X100-11N
IO2 | LM2596S-5 | LM2596S | TO263-5
J4 | DX07S024JJ3R1300 DX07S024JJ3R1300 | JAE_DX07S024JJ3R1300
L1 | 22UH | INDUCTOR | INDUCTOR_L0630
LED1 | | LEDCHIP-LED0603 | CHIP-LED0603
LED2 | | LEDCHIP-LED0603 | CHIP-LED0603
LED3 | | LEDCHIP-LED0603 | CHIP-LED0603
LED4 | | LEDCHIP-LED0603 | CHIP-LED0603
LED5 | | LEDCHIP-LED0603 | CHIP-LED0603
R1 | 470 | R-EU_R0603 | R0603
R2 | 470 | R-EU_R0603 | R0603

R3 | 470 | R-EU_R0603 | R0603
R4 | 470 | R-EU_R0603 | R0603
R5 | 470 | R-EU_R0603 | R0603
R6 | 470 | R-EU_R0603 | R0603
R7 | 470 | R-EU_R0603 | R0603
R8 | 1.13k | R-EU_R0603 | R0603
R9 | 470 | R-EU_R0603 | R0603
R10 | 470 | R-EU_R0603 | R0603
R11 | 1.13k | R-EU_R0603 | R0603
R12 | 470 | R-EU_R0603 | R0603
R13 | 470 | R-EU_R0603 | R0603
R14 | 470 | R-EU_R0603 | R0603
R15 | 4.7k | R-EU_R0603 | R0603
R16 | 3k | R-EU_R0603 | R0603
RPI | RPI-ZERO | RPI-ZERO | RASPBERRYPI
S1 | BUTTON | BUTTON | BUTTON
S2 | BUTTON | BUTTON | BUTTON
S3 | BUTTON | BUTTON | BUTTON
S4 | BUTTON | BUTTON | BUTTON
S5 | BUTTON | BUTTON | BUTTON
S6 | BUTTON | BUTTON | BUTTON
TP1 | TPB2,54 | TPB2,54 | B2,54
TP2 | TPB2,54 | TPB2,54 | B2,54
U$3 | MCP3008SL | MCP3008SL | SO16
U$10 | 1P2T | 1P2T | 1P2T
U1 | JOYSTICKPTH | JOYSTICKPTH | JOYSTICK
Z1 | 1n5824 | SUPRESSOR_TVS-UD-SMAJ | SUPRESSOR_SMAJ

PRÍLOHA D

CENOVÁ KALKULÁCIA NÁKLADOV

DPS | 27 €
Súčiastky: | 127,09 €
- DCDC prevodník | 6,26 €
- USB-C | | 2,14 €
- 2x Nabíjacie moduly | 3,16 €
- 10x Prepínač | 0,51 €
- ADC prevodník | 2,56 €
- Držiak na batérie | 5,42 €
- Poistka | | 0,63 €
- Raspberry Pi Zero 2 W | 16,10 €
- LCD displej | 54,94 €
- HDMI kábel | 1,92 €
- HDMI adaptér | 3,50 €
- Raspberry Pi Zero male header | 1,37 €
- mini HDMI adaptér | 3,34 €
- 3,5 mm audio jack kábel | 4,96 €
- OEM USB napájací kábel | 3,79 €
- Dátový kábel USB do micro USB 3,40 €
- Kondenzátory
- | 20x 100 nF | 0,16 €
- | 5x 220 uF | 4,33 €
- Rezistory
- | 20x 470 | 0,42 €
- | 20x 1,13k | 0,25 €
- | 20x 4,7k | 0,11 €
- | 20x 3k | 0,09 €
- | 20x 10k | 0,09 €
- 10x LED | 0,91 €
- 5x schottkyho dióda | 2,01 €
- 5x cievka 22 uH | 4,72 €

Konštrukčné prvky

Creality EN-PLA 1,75 mm čierny 15,90 €

Spolu | 169,99 €

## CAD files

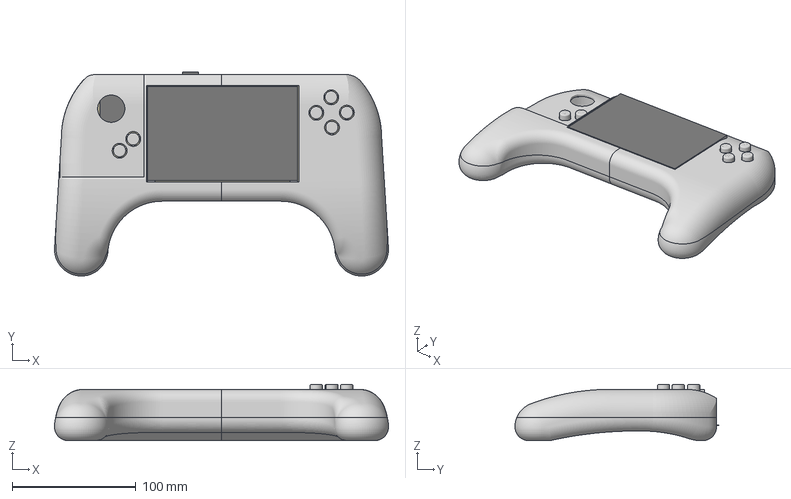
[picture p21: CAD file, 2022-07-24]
Handheld_5 Model.3mf
269.6 x 164.7 x 45.3 mm
A
B
Board
Display
LowerPart (1)
LowerPart
Select
Start
UpperPart (1)
UpperPart
X
Y

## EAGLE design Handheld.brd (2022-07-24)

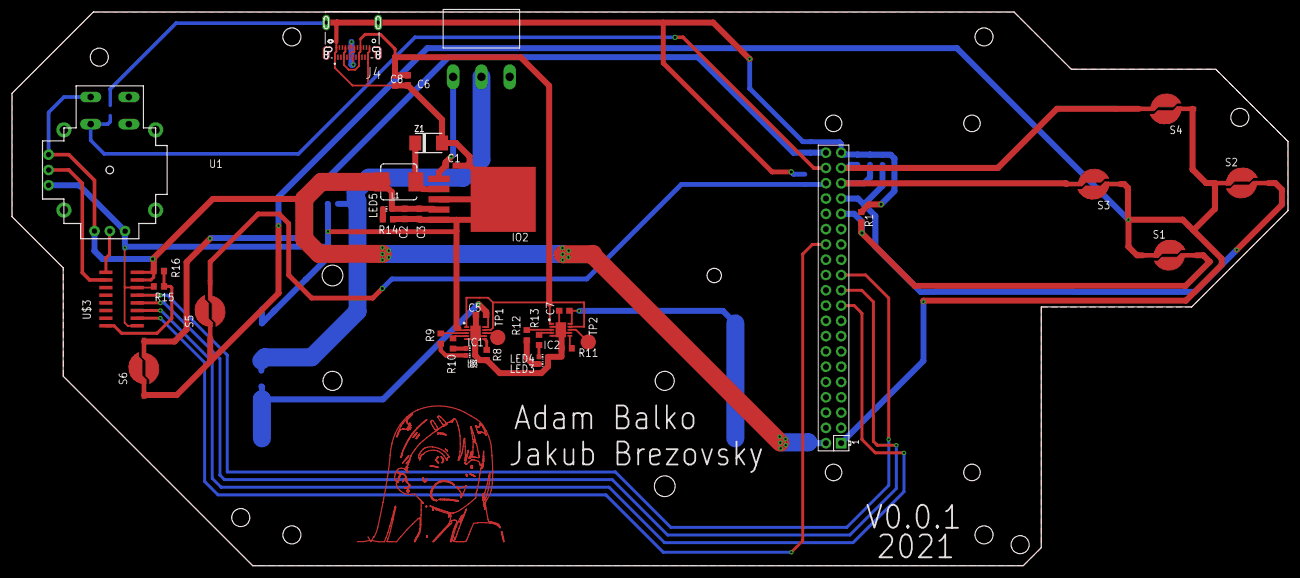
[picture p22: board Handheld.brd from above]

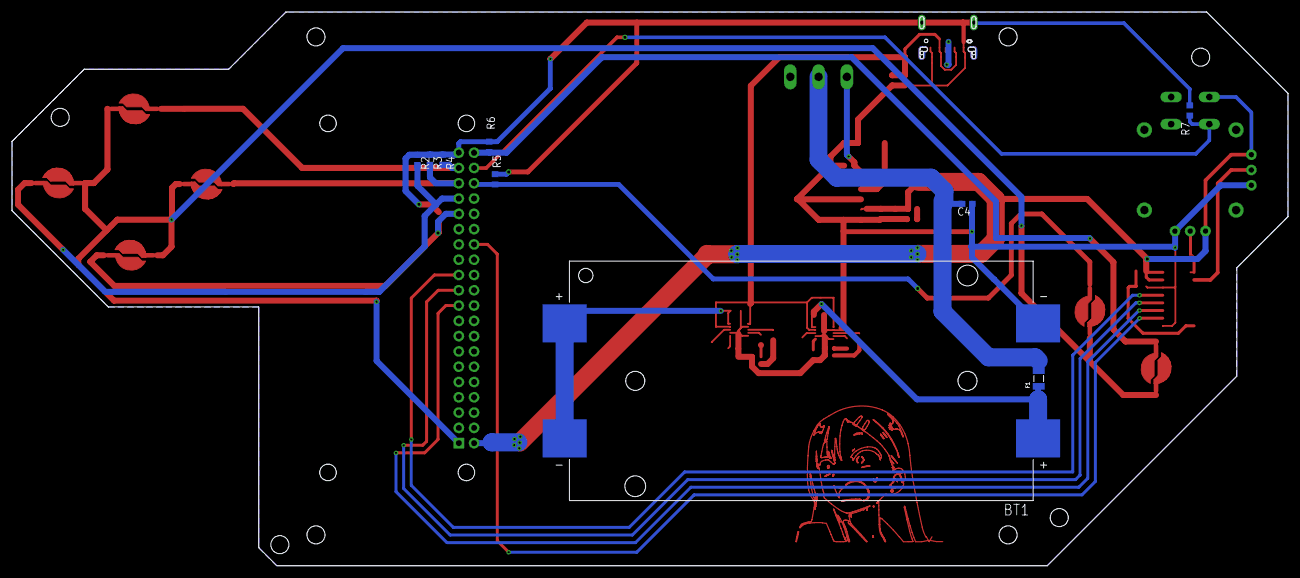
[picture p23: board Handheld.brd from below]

Board: 2 copper layers, 212.0 x 92.0 mm, 49 parts (9 on the bottom side), 38 nets.

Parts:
BT1: 1048P; BAT_1048P
C1: 330n; C0603
C2: 220n; C0603
C3, C5, C6, C7, C8: 100nF; C0603
C4: 100n; C0603
F1: 5A; 3413.0113.22
IC1, IC2: BQ24080DRCR; SON50P300X300X100-11N
IO2: LM2596S-5; TO263-5
J4: DX07S024JJ3R1300; JAE_DX07S024JJ3R1300
L1: 22UH; INDUCTOR_L0630
LED1, LED2, LED3, LED4, LED5: CHIP-LED0603
R1, R2, R3, R4, R5, R6, R7, R9, R10, R12, R13, R14: 470; R0603
R8, R11: 1.13k; R0603
R15: 4.7k; R0603
R16: 3k; R0603
RPI: RPI-ZERO; RASPBERRYPI_BASTELSTUBE_V13_RASPI_BOARD_B+_FULL
S1, S2, S3, S4, S5, S6: BUTTON
TP1, TP2: TPB2,54; B2,54
U1: JOYSTICKPTH; JOYSTICK
U$3: MCP3008SL; SO16
U$10: 1P2T
Z1: 1n5824; SUPRESSOR_SMAJ

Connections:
+3V3: RPI.1, S1.1, S2.1, S3.1, S4.1, S5.1, S6.1
+5V: C2.1, C3.1, IO2.4, L1.2, LED5.A, R16.1, RPI.2, U1.B1A, U1.H1, U1.V1, U$3.15, U$3.16
A: R1.2, RPI.31, S1.2
B: R2.2, RPI.33, S2.2
BAT_1: BT1.1+, C5.1, F1.1, IC1.10
BAT_2: BT1.1-, BT1.2+, C7.1, IC2.10
BAT_OUT: C1.1, IO2.1, U$10.P$1
CS: RPI.28, U$3.10
FUSE: C4.2, F1.2, U$10.P$2
GND: BT1.2-, C1.2, C2.2, C3.2, C4.1, C5.2, C6.2, C7.2, C8.2, IC1.2, IC1.5, IC1.7, IC1.11, IC2.2, IC2.5, IC2.7, IC2.11, IO2.3, IO2.5, IO2.6, J4.A1, J4.A12, J4.B1, J4.B12, J4.S1, J4.S2, LED1.A, LED2.A, LED3.A, LED4.A, R1.1, R2.1, R3.1, R4.1, R5.1, R6.1, R7.1, R8.1, R11.1, R14.2, R15.2, RPI.39, U1.H3, U1.V3, U$3.9, U$3.14, Z1.A
JS: R7.2, RPI.38, U1.B2A
MISO: RPI.21, U$3.12
MOSI: RPI.19, U$3.11
unnamed: U1.H2, U$3.1
unnamed: LED5.C, R14.1
unnamed: U1.V2, U$3.2
unnamed: IC1.6, R8.2
unnamed: IC1.4, R10.2
unnamed: IC1.3, R9.2
unnamed: LED1.C, R9.1
unnamed: LED2.C, R10.1
unnamed: IC2.6, R11.2
unnamed: IC2.4, R13.2
unnamed: IC2.3, R12.2
unnamed: LED3.C, R12.1
unnamed: LED4.C, R13.1
unnamed: IC1.8, TP1.TP
unnamed: IC2.8, TP2.TP
unnamed: IO2.2, L1.1, Z1.C
SCLK: RPI.23, U$3.13
SELECT: R6.2, RPI.40, S6.2
START: R5.2, RPI.36, S5.2
USB_IN: C6.1, C8.1, IC1.1, IC1.9, IC2.1, IC2.9, J4.A4, J4.A9, J4.B4, J4.B9
USB_OUT_3_N: J4.A7, J4.B7
USB_OUT_3_P: J4.A6, J4.B6
V_DEL: R15.1, R16.2, U$3.8
X: R3.2, RPI.35, S3.2
Y: R4.2, RPI.37, S4.2

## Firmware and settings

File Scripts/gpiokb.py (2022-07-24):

import RPi.GPIO as GPIO
import keyboard
import time
import busio
import digitalio
import board
import adafruit_mcp3xxx.mcp3008 as MCP
from adafruit_mcp3xxx.analog_in import AnalogIn

# Nastavenie režimu adresovania GPIO pinov
# BCM = relatívne číslo pinu
# BOARD = fyzické číslo pinu
GPIO.setmode(GPIO.BCM)

# Nastavenie vstupných pinov
GPIO.setup((6, 13, 16, 19, 20, 21, 26), GPIO.IN)

time.sleep(20)

# Definícia GPIO pinov pre SPI
spi = busio.SPI(clock=board.D11, MISO=board.D9, MOSI=board.D10)
cs = digitalio.DigitalInOut(board.D8)
mcp = MCP.MCP3008(spi, cs)


# Nekonečná slučka
while 1:
    # Detekcia stlačenia tlačidiel
    if GPIO.input(6): keyboard.press('enter')
    if GPIO.input(13): keyboard.press('l')
    if GPIO.input(19): keyboard.press('space')
    if GPIO.input(16): keyboard.press('esc')
    if GPIO.input(26): keyboard.press('i')
    if GPIO.input(20): keyboard.press('z')
    if GPIO.input(21): keyboard.press('tab')

    # Detekcia pustenia tlačidiel
    if not GPIO.input(6): keyboard.release('enter')
    if not GPIO.input(13): keyboard.release('l')
    if not GPIO.input(19): keyboard.release('space')
    if not GPIO.input(16): keyboard.release('esc')
    if not GPIO.input(26): keyboard.release('i')
    if not GPIO.input(20): keyboard.release('z')
    if not GPIO.input(21): keyboard.release('tab')

    # Čítanie hodnôt z ADC
    xAxis = AnalogIn(mcp, MCP.P0)
    yAxis = AnalogIn(mcp, MCP.P1)

    # Priradenie stlačenej 
    # Value 65472 => úplné vychýlenie páčky hore/vľavo
    # Value 0 => Úplné vychýlenie páčky dole/vpravo
    if xAxis.value > 52000: keyboard.press("left")
    if xAxis.value < 12000: keyboard.press("right")
    if yAxis.value > 52000: keyboard.press("up")
    if yAxis.value < 12000: keyboard.press("down")

    if xAxis.value < 52000: keyboard.release("left")
    if xAxis.value > 12000: keyboard.release("right")
    if yAxis.value < 52000: keyboard.release("up")
    if yAxis.value > 12000: keyboard.release("down")

    time.sleep(0.008)

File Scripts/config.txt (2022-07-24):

# For more options and information see
# http://rpf.io/configtxt
# Some settings may impact device functionality. See link above for details

# uncomment if you get no picture on HDMI for a default "safe" mode
#hdmi_safe=1

# uncomment this if your display has a black border of unused pixels visible
# and your display can output without overscan
#disable_overscan=1

# uncomment the following to adjust overscan. Use positive numbers if console
# goes off screen, and negative if there is too much border
#overscan_left=16
#overscan_right=16
#overscan_top=16
#overscan_bottom=16

# uncomment to force a console size. By default it will be display's size minus
# overscan.
#framebuffer_width=1280
#framebuffer_height=720

# uncomment if hdmi display is not detected and composite is being output
#hdmi_force_hotplug=1

# uncomment to force a specific HDMI mode (this will force VGA)
hdmi_group=2
hdmi_mode=87

# uncomment to force a HDMI mode rather than DVI. This can make audio work in
# DMT (computer monitor) modes
#hdmi_drive=2

# uncomment to increase signal to HDMI, if you have interference, blanking, or
# no display
#config_hdmi_boost=4

# uncomment for composite PAL
#sdtv_mode=2

#uncomment to overclock the arm. 700 MHz is the default.
#arm_freq=800

# Uncomment some or all of these to enable the optional hardware interfaces
#dtparam=i2c_arm=on
#dtparam=i2s=on
dtparam=spi=on

# Uncomment this to enable infrared communication.
#dtoverlay=gpio-ir,gpio_pin=17
#dtoverlay=gpio-ir-tx,gpio_pin=18

# Additional overlays and parameters are documented /boot/overlays/README

# Enable audio (loads snd_bcm2835)
dtparam=audio=on

[pi4]
# Enable DRM VC4 V3D driver on top of the dispmanx display stack
#dtoverlay=vc4-fkms-v3d
max_framebuffers=2

[all]
#dtoverlay=vc4-fkms-v3d

max_usb_current=1
hdmi_cvt 800 480 60 6 0 0 0


[all]
#dtoverlay=vc4-kms-v3d
